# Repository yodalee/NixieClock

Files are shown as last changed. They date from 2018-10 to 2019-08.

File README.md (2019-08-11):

Nixie Clock
-----------

All data about my nixie tube implementation:

## The Nixie Clock

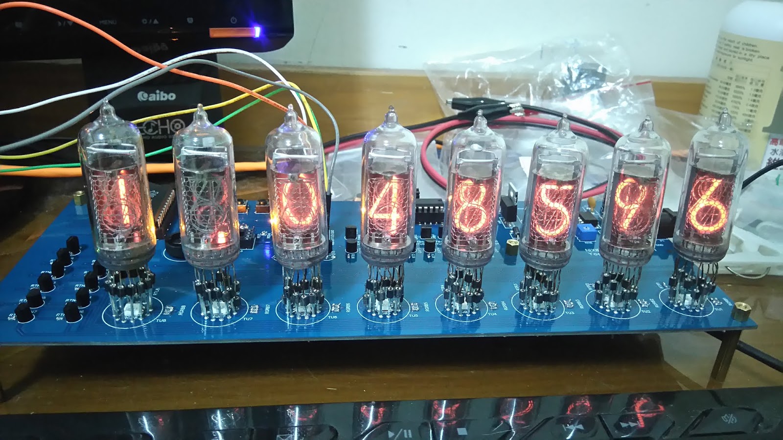
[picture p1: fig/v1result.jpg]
Nixie Clock


Some demo video:  
[Test Tube](https://www.youtube.com/watch?v=yUsdp3tUh6w)  
[Change WorldLine](https://www.youtube.com/watch?v=egiKm6L4Y-A)  

## Repository Structure
├── fig  
├── hardware  
│   ├── BOMmanual\_v1.0.1.csv : BOM file manually written  
│   ├── BOM\_v1.0.1.tsv : BOM file export from EasyEDA  
│   ├── layout  
│   │   ├── gerber\_v1.01 : v1.01 Gerber file  
│   │   └── gerber\_v1.02 : v1.02 Gerber file  
│   └── schematic : Schematic for [Altium](https://www.altium.com) and [EasyEDA](https://easyeda.com)  
└── software  
&emsp;&emsp;├── DS1309 : Set time into DS1309  
&emsp;&emsp;├── HC238test : Test 74HC238 works fine.  
&emsp;&emsp;├── HC4514test : Test 74HC4514 works fine.  
&emsp;&emsp;├── nixie : Source code that right now runs on my Nixie Clock  
&emsp;&emsp;├── pin1.01.h : Macro setting for v1.01 board
&emsp;&emsp;└── pin1.02.h : Macro setting for v1.02 board

## Usage
1. Order the hardware board using the Gerber file.
2. Buy materials according to BOM file.
3. The software, please copy pin\<version\>.h to pin.h inside each directory.

## CAUTION

* The BOM table may have some difference that I did not notice, please check before you order.
* v1.02 only draw on easyEDA, it does not get fabricated and tested. It might have design problem and cannot work normally. Use it carefully.

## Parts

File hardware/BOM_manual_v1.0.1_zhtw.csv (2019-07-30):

Item | Quantities | Comment
Tube
Nixie Tube | 8 | IN14
IC 圓孔長腳座 | 104 | 8*13
Nixie 限流電阻 22K | 8 | 0603
Nixie 限流電阻 51K | 16 | 0603
驅動
MPSA42 | 20
MPSA92 | 8
電阻 51K | 20 | 0603
電阻 470K | 8 | 0603
電阻 1M | 8 | 0603
控制
CD4514B 4-16 demux | 1
IC座 DIP24-600 | 1
74HC238 3-8 demux | 1
IC座 DIP16 | 1
Atmega328P | 1
IC座 DIP28 | 1
按鍵開關 | 3 | 6*6*5
排母 | 1 | x5
電阻 10k | 3 | 0603
LED
LED RGB | 8 | 5050
LED Yellow | 1 | 0603
電阻 270 ohm | 17 | 0603
電阻 620 ohm | 8 | 0603
2N2222 | 3
電阻 22k | 3 | 0603
電源
12V 變壓器 | 1
接腳 | 1 | Jack
扳動開關 | 1
燒錄用
晶體振盪器 16MHz | 1
陶瓷電容 15 pF | 2
電阻 1K | 1 | Axial
Arduino board | 1 | Any type
公對公杜邦線 | >5
RTC
DS1307 | 1
IC座 DIP8 | 1
鋰電池 CR1220 3V | 1
鋰電池座 | 1
電阻 2.2K | 2 | 0603
晶體振盪器32.768 KHz | 1
高壓電路
MC34063A | 1
電解電容250V 10uF | 1
IRF840 | 1 | L-R: GDS
2N2907 | 1 | PNP, L-R: CBE
陶瓷電容222 | 1 | 2.2 nF
陶瓷電容104 | 1 | 100 nF
FR104 二極體 | 1
1N914/4148 高速二極體 | 1
68/100 uH 電感 | 1
電阻 1K | 1
可變電阻 3362 | 1 | 2K, 3362P-1-202
精密電阻 511K | 1
精密電阻 3.3K | 1
電阻 1R | 5 | 1206
12V/5V 電路
78M05 | 1
陶瓷電容 104 | 2
電阻 10K | 1 | 0603
電解電容25V 470uF | 1
穩壓電容 103 | 4 | 0603
Jumper | 1
短路器 | 1
其他
銅柱 | 8
22k 電阻 | 1 | 測試燈管用
附鱷魚夾線 | 1-2 | 測試燈管用
工具
單芯線 | 1
焊錫等 | 1
麵包板 | 1 | 如果想測的話
三用電錶 | 1
尖嘴鉗 | 1
斜口鉗 | 1

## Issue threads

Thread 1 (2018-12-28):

An if-block bug that is similar to Apple’s SSL "goto fail" bug

johnjohnlin, 2018-12-28:
Hello, it seems that there should be a pair of brace here.
https://github.com/yodalee/NixieClock/blob/master/software/DS1309/DS1309.ino#L40

```cpp
  if(timeStatus() != timeSet) // Here
    digitalWrite(LED, HIGH);
    delay(100);
    digitalWrite(LED, LOW);
```

yodalee, 2019-01-03:
Fixed.
Though the brace actually not affect the function :)

Closed 2019-01-03.

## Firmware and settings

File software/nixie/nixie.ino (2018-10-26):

#include "pin.h"
#include <Wire.h>
#include <Time.h>
#include <DS1307RTC.h>
#define DS1307_ADDR (0x68)
#define RAM_OFFSET  (8)
#define NTUBE       (8)

// due to hardware design error, 1-9 is reversed
byte mapNum(byte num) {
  if (num > 0 && num < 10) {
    return 10-num;
  } else {
    return num;
  }
}

// Random related
unsigned long seed() {
  unsigned long ret = 0;
  int value;
  for (int i = 0; i < 8; i++) {
    value = analogRead(EMPTY);
    ret |= value & 0xf;
    ret <<= 4;
  }
  return ret;
}

void xorshift32(unsigned long *state) {
  *state ^= *state << 13;
  *state ^= *state >> 17;
  *state ^= *state << 5;
}

// Write number and Write Tube
void writeNum(byte num) {
  if (num >= 12) {
    digitalWrite(DISPLAY_E, HIGH);
  } else {
    byte mappedNum = mapNum(num);
    digitalWrite(DISPLAY_E, LOW);
    digitalWrite(DISPLAY_3, (mappedNum >> 3) & 0x1);
    digitalWrite(DISPLAY_2, (mappedNum >> 2) & 0x1);
    digitalWrite(DISPLAY_1, (mappedNum >> 1) & 0x1);
    digitalWrite(DISPLAY_0, (mappedNum >> 0) & 0x1);
  }
}

void writeTube(byte tube) {
  digitalWrite(TUBE_2, (tube >> 2) & 0x1);
  digitalWrite(TUBE_1, (tube >> 1) & 0x1);
  digitalWrite(TUBE_0, (tube >> 0) & 0x1);
}

// Button Related
const unsigned long debounceDelay = 50;
const unsigned short divergenceDelay = 6000;

bool detectBtn1() {
  static unsigned long lastDebounceTime1 = 0;
  static int btnState1;
  static int lastButtonState1 = HIGH;

  int reading = digitalRead(BTN1);
  unsigned long current = millis();

  if (reading != lastButtonState1) {
    lastDebounceTime1 = current;
  }
  if (current - lastDebounceTime1 > debounceDelay) {
    if (reading != btnState1) {
      btnState1 = reading;

      if (btnState1 == LOW) {
        return true;
      }
    }
  }
  lastButtonState1 = reading;
  return false;
}

bool detectBtn2() {
  static unsigned long lastDebounceTime2 = 0;
  static int btnState2;
  static int lastButtonState2 = HIGH;

  int reading = digitalRead(BTN2);
  unsigned long current = millis();

  if (reading != lastButtonState2) {
    lastDebounceTime2 = current;
  }
  if (current - lastDebounceTime2 > debounceDelay) {
    if (reading != btnState2) {
      btnState2 = reading;

      if (btnState2 == LOW) {
        return true;
      }
    }
  }
  lastButtonState2 = reading;
  return false;
}

// data to be displayed by tube
byte display[NTUBE];
// data for divergence change
byte divergence[NTUBE];
byte newDivergence[NTUBE];
byte display_buf[NTUBE];
short stop_ms[NTUBE] = {5000, 4500, 4000, 3500, 3000, 2500, 2000, 1500};
unsigned long startTime;
// use ledState and enum
// allow only one led is on (current consumption)
enum { RED, GREEN, BLUE, BLACK, LENLED };
byte ledState;
// toggle, secCount: update by RTC interrupt
volatile byte toggle;
unsigned long secCount;

unsigned long randomnum;
// state is the highest control variable
enum { NONE, ROUND, TIME, DATE, DIVERGENCE, BEFORE, CHANGING };
byte state;

int hexrand(byte maxvalue) {
  xorshift32(&randomnum);
  while((randomnum & 0xf) >= maxvalue) {
    xorshift32(&randomnum);
  }
  return (randomnum & 0xf);
}

void ISR_RTC() {
  toggle = !toggle;
  ++secCount;
}

void setupRTC() {
  Wire.begin();
  Wire.beginTransmission(DS1307_ADDR);
  Wire.write(0x07);
  Wire.write(0x10);  // Set Square Wave to 1 Hz
  Wire.endTransmission();

  setSyncProvider(RTC.get);

  if(timeStatus() != timeSet)
    digitalWrite(LED_Y, HIGH);
    delay(100);
    digitalWrite(LED_Y, LOW);
}

void writeNVRam(byte offset, byte *buf, byte nBytes) {
  Wire.beginTransmission(DS1307_ADDR);
  Wire.write(RAM_OFFSET + offset);
  for (int i = 0; i < nBytes; i++) {
    Wire.write(buf[i]);
  }
  Wire.endTransmission();
}

void readNVRam(byte offset, byte *buf, byte nBytes) {
  Wire.beginTransmission(DS1307_ADDR);
  Wire.write(RAM_OFFSET + offset);
  Wire.endTransmission();
  Wire.requestFrom( (uint8_t)DS1307_ADDR, nBytes);
  for (byte i = 0; i < nBytes; i++) {
    buf[i] = Wire.read();
  }
}

void setup() {
  // Pin Tube
  pinMode(TUBE_0, OUTPUT);
  pinMode(TUBE_1, OUTPUT);
  pinMode(TUBE_2, OUTPUT);

  // Pin Num
  pinMode(DISPLAY_E, OUTPUT);
  pinMode(DISPLAY_0, OUTPUT);
  pinMode(DISPLAY_1, OUTPUT);
  pinMode(DISPLAY_2, OUTPUT);
  pinMode(DISPLAY_3, OUTPUT);

  // Pin BTN
  pinMode(BTN1, INPUT);
  pinMode(BTN2, INPUT);

  // Pin LED
  pinMode(LED_Y, OUTPUT);
  pinMode(LED_G, OUTPUT);
  pinMode(LED_B, OUTPUT);
  pinMode(LED_R, OUTPUT);

  // Pin RTC
  pinMode(RTC_SQW, INPUT_PULLUP);

  // setup RTC
  setupRTC();
  attachInterrupt(digitalPinToInterrupt(RTC_SQW), ISR_RTC, RISING);
  readNVRam(0, divergence, NTUBE);

  toggle = 0;
  secCount = 0;
  randomnum = seed();
  state = ROUND;
}

// set Date to display
void setDisplayDate() {
  int y = year();
  int m = month();
  int d = day();
  display[0] = d % 10;
  display[1] = d / 10;
  display[2] = m % 10;
  display[3] = m / 10;
  display[4] = y % 10;
  display[5] = (y / 10) % 10;
  display[6] = (y / 100) % 10;
  display[7] = y / 1000;
}

// set Time to display
void setDisplayTime() {
  int h = hour();
  int m = minute();
  int s = second();
  display[0] = s % 10;
  display[1] = s / 10;
  display[2] = (secCount & 0x1)? 10 : 11;
  display[3] = m % 10;
  display[4] = m / 10;
  display[5] = (secCount & 0x1)? 10 : 11;
  display[6] = h % 10;
  display[7] = h / 10;
}

// output display content to nixie tube
void updateTube() {
  for (int tube = 0; tube < NTUBE; tube++) {
    writeTube(tube);
    writeNum(display[tube]);
    delay(2);
  }
}

// set LED state by led variable
void updateLED()
{
  static byte lastState = LENLED;
  if (ledState == lastState) {
    return;
  }
  lastState = ledState;
  // close all first, prevent short-time high current
  digitalWrite(LED_G, LOW);
  digitalWrite(LED_B, LOW);
  digitalWrite(LED_R, LOW);
  // open light based on state
  switch (ledState) {
    case GREEN:
      digitalWrite(LED_G, HIGH);
      return;
    case BLUE:
      digitalWrite(LED_B, HIGH);
      return;
    case RED:
      digitalWrite(LED_R, HIGH);
      return;
    default:
      return;
  }
}


void loop() {
  byte btn1 = detectBtn1();
  byte btn2 = detectBtn2();
  // press btn1 or every 300 secs will have divergence change
  if ((btn1 && !btn2) ||
      (secCount % 300 == 0 && secCount != 0)) {
    if (state != NONE) {
      state = BEFORE;
      startTime = millis();
      // generate new divergence
      // TODO a better divergence random
      for (byte i = 0; i < NTUBE; i++) {
        newDivergence[i] = hexrand(10);
      }
      newDivergence[6] = 10;
      writeNVRam(0, newDivergence, NTUBE);
    }
  }

  if (btn2 && !btn1) {
    state++;
    if (state >= BEFORE) { state = 0; }
  }

  byte sec = second();
  ledState = minute() % 4;
  unsigned long current = millis();
  bool all_after = true;
  switch (state) {
    case ROUND:
      if (sec < 25) {
        setDisplayDate();
      } else if (sec < 50) {
        setDisplayTime();
      } else {
        memcpy(display, divergence, NTUBE);
      }
      break;
    case TIME:
      setDisplayTime();
      break;
    case DATE:
      setDisplayDate();
      break;
    case DIVERGENCE:
      memcpy(display, divergence, NTUBE);
      break;
    case BEFORE: // stay BEFORE after 6 sec
      memcpy(display, divergence, NTUBE);
      ledState = (current >> 8) & 0x3;
      if (current - startTime > divergenceDelay) {
        state = CHANGING;
      }
      break;
    case CHANGING:
      ledState = RED;
      for (int i = 0; i < 8; i++) {
        if (current - startTime >= stop_ms[i] + divergenceDelay) {
          display[i] = newDivergence[i];
        } else {
          display[i] = hexrand(10);
          all_after = false;
        }
      }
      if (all_after) {
        ledState = BLUE;
        memcpy(divergence, newDivergence, 8);
      }
      if (current - startTime >= divergenceDelay + 10000) {
        state = ROUND;
      }
      break;
    default:
      memset(display, 12, 8);
      ledState = BLACK;
      break;
  }

  // update LED
  updateLED();
  // leave updateTube here, unless tube cannot keep on
  updateTube();
  digitalWrite(LED_Y, toggle);
}

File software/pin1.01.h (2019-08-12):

// Pin Tube
#define TUBE_0 (6)
#define TUBE_1 (7)
#define TUBE_2 (8)

// Pin Num
#define DISPLAY_0 (9)  // LSB
#define DISPLAY_1 (10)
#define DISPLAY_2 (11)
#define DISPLAY_3 (12) // MSB
#define DISPLAY_E (13)

// BTN
#define BTN1 (A0)
#define BTN2 (A1)

// LED
#define LED_Y (A2)
#define LED_G (3)
#define LED_R (4)
#define LED_B (5)

// RTC
#define RTC_SQW (2)

// Other
#define EMPTY (A3)

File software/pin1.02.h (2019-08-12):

// Pin Tube
#define TUBE_0 (3)
#define TUBE_1 (4)
#define TUBE_2 (5)

// Pin Num
#define DISPLAY_0 (6)  // LSB
#define DISPLAY_1 (7)
#define DISPLAY_2 (8)
#define DISPLAY_3 (9)  // MSB
#define DISPLAY_E (10)

// BTN
#define BTN1 (A0)
#define BTN2 (A1)

// LED
#define LED_Y (A2)
#define LED_G (13)
#define LED_R (12)
#define LED_B (11)

// RTC
#define RTC_SQW (2)

// Other
#define EMPTY (A3)

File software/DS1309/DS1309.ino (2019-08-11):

/*
  DS1309

  Write time into DS1309 when button 1 is pressed
*/

#include "pin.h"
#include <Wire.h>
#include <Time.h>
#include <DS1307RTC.h>

const unsigned long debounceDelay = 50;

bool detectBtn1() {
  static unsigned long lastDebounceTime1 = 0;
  static int btnState1;
  static int lastButtonState1 = HIGH;

  int reading = digitalRead(BTN1);
  unsigned long current = millis();

  if (reading != lastButtonState1) {
    lastDebounceTime1 = current;
  }
  if (current - lastDebounceTime1 > debounceDelay) {
    if (reading != btnState1) {
      btnState1 = reading;

      if (btnState1 == LOW) {
        return true;
      }
    }
  }
  lastButtonState1 = reading;
  return false;
}

void setup()  {
  Serial.begin(115200);

  setSyncProvider(RTC.get);

  if(timeStatus() != timeSet) {
    digitalWrite(LED_Y, HIGH);
    delay(100);
    digitalWrite(LED_Y, LOW);
  }
}

void loop()
{
  if (detectBtn1()) {
    setTime();
    digitalWrite(LED_Y, HIGH);
    delay(1000);
    digitalWrite(LED_Y, LOW);
  }
}

// set time to hard-written time
void setTime()
{
  int y = 2018;
  int M = 10;
  int d = 14;
  int h = 22;
  int m = 45;
  int s = 0;

  tmElements_t tm;
  tm.Year = y - 1970; // start from 1970
  tm.Month = M;
  tm.Day = d;
  tm.Hour = h;
  tm.Minute = m;
  tm.Second = s;
  setTime(makeTime(tm));
  RTC.set(makeTime(tm));
}

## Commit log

2018-10-15 add schematic of easyEDA and Altium
2018-10-17 add HC238 and HC4514 tester
    press button 1 to open each output of HC chip
2018-10-18 add BOM table
    [BOM_v1.0.1.tsv, BOMmanual_v1.0.1.csv]
2018-10-26 add v1.01 gerber file
    [BoardOutline.GKO, BottomLayer.GBL, BottomSolderMaskLayer.GBS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]
2018-12-02 add v1.02 layout and schematic
    [BoardOutline.GKO, BottomLayer.GBL, BottomSolderMaskLayer.GBS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]
2019-01-03 fix if without brace error
    [DS1309.ino]
2019-07-30 update BOM table
    [BOM_manual_v1.0.1_zhtw.csv, BOM_v1.0.2.tsv, BOMmanual_v1.0.1.csv]
2019-08-11 use same code with different pin setting
2019-08-12 fix wrong pin setting in HC4514test
    [HC4514test.ino, pin1.01.h, pin1.02.h]
